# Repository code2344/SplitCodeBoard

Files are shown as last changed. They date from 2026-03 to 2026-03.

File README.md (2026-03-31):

# SplitCodeBoard

SplitCodeBoard is a split keyboard with a macropad designed for programming. I made this because I do not have any good keyboards at home, and the idea of a split keyboard appealed to me. 
SplitCodeBoard was made as part of Hack Club Stasis. "SplitCodeBoard.step" is the PCB STEP, the pcb with case is in 'SplitCodeBoard.step_STEP.zip'.
Here are some images: <br>
Macropad:<br>
Screenshot 2026-03-31 at 4 16 33 pm<br>
Left keyboard half:<br>
Screenshot 2026-03-31 at 4 17 09 pm<br>
Right keyboard half:<br>
Screenshot 2026-03-31 at 4 17 52 pm<br>
Side schematic:<br>
Screenshot 2026-03-31 at 4 19 14 pm<br>
Main and macropad schematic:<br>
Screenshot 2026-03-31 at 4 18 46 pm<br>
PCB:<br>
Screenshot 2026-03-31 at 4 20 12 pm<br>

## BOM
| Name | Purpose | Quantity | Total Cost (USD) | Link | Distributor |
|---|---|---|---|---|---|
| MCP23017-E/SO | GPIO expansion for the nRF52840 on the keyboard sides | 2 | 3.24 | [Link to listing](https://www.digikey.com/en/products/detail/microchip-technology/MCP23017-E-SO/894271) | Digikey |
| Seeed Xiao nRF52840 | Microcontrollers | 3 | 48.54 | [Link to listing](https://www.digikey.com.au/en/products/detail/seeed-technology-co-ltd/102010448/16652893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) | Digikey |
| Kailh PG1350 Choc V1 70PCS Mechanical Keyboard Switch Kailh Low Profile Switches Chocolate Mechanical Keyboard Switch RGB SMD 5-Pin Kailh Switches | Switches for the keyboard | 1 | 49.98 | [Link to listing](https://snapklik.com/en-au/product/kailh-pg1350-choc-v1-70pcs-mechanical-keyboard-switch-kailh-low-profile-switches-chocolate-mechanical-keyboard-switch-rgb-smd-5-pi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) | Snapklik |
| Kailh Choc Hotswap Sockets (Pack of 10) | Hotswap sockets for the keys | 7 | 24.5 | [Link to listing](https://keebd.com/products/kailh-choc-hotswap-sockets?variant=40393453338776&country=AU&currency=AUD) | KEEBD |
| PURFIELD 3.7V 501012 401010 401012 400909 Polymer Lithium Battery Suitable for I7 i8 i9 i10 Earphone Headset MP3 MP4 Toy GPS | Batteries for each half of the keyboard | 20 | 21.2 | [Link to listing](https://www.aliexpress.com/item/1005008747431465.html) | Aliexpress |
| 1N5819HW-7-F | Diodes for the key matrix | 70 | 17.15 | [Link to listing](https://www.digikey.com.au/en/products/detail/diodes-incorporated/1N5819HW-7-F/814970) | Digikey |

## Licensing

This repository uses split licensing by content type:

- Firmware and firmware configuration (for example, files under `zmk-config/`) are licensed under GNU Affero General Public License v3.0 only (`AGPL-3.0-only`).
- Hardware design files (for example, KiCad schematics/PCBs, footprints, and 3D mechanical files) are licensed under CERN Open Hardware Licence Version 2 - Strongly Reciprocal (`CERN-OHL-S-2.0`).

See the root `LICENSE` file for full licensing scope and notices.

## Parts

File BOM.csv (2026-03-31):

Name | Purpose | Quantity | Total Cost (USD) | Link | Distributor
MCP23017-E/SO | GPIO expansion for the nRF52840 on the keyboard sides | 2 | 3.24 | https://www.digikey.com/en/products/detail/microchip-technology/MCP23017-E-SO/894271 | Digikey
Seeed Xiao nRF52840 | Microcontrollers | 3 | 48.54 | https://www.digikey.com.au/en/products/detail/seeed-technology-co-ltd/102010448/16652893 | Digikey
Kailh PG1350 Choc V1 70PCS Mechanical Keyboard Switch Kailh Low Profile Switches Chocolate Mechanical Keyboard Switch RGB SMD 5-Pin Kailh Switches | Switches for the keyboard | 1 | 49.98 | https://snapklik.com/en-au/product/kailh-pg1350-choc-v1-70pcs-mechanical-keyboard-switch-kailh-low-profile-switches-chocolate-mechanical-keyboard-switch-rgb-s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 | Snapklik
Kailh Choc Hotswap Sockets (Pack of 10) | Hotswap sockets for the keys | 7 | 24.50 | https://keebd.com/products/kailh-choc-hotswap-sockets?variant=40393453338776&country=AU&currency=AUD | KEEBD
PURFIELD 3.7V 501012 401010 401012 400909 Polymer Lithium Battery Suitable for I7 i8 i9 i10 Earphone Headset MP3 MP4 Toy GPS | Batteries for each half of the keyboard | 20 | 21.20 | https://www.aliexpress.com/item/1005008747431465.html | Aliexpress
1N5819HW-7-F | Diodes for the key matrix | 70 | 17.15 | https://www.digikey.com.au/en/products/detail/diodes-incorporated/1N5819HW-7-F/814970 | Digikey

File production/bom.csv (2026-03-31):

Designator | Footprint | Quantity | Value | LCSC Part #
D1, D10, D11, D12, D13, D14, D15, D16, D17, D18, D19, D2, D20, D21, D22, D23, D24, D25, D26, D27, D28, D29, D3, D30, D31, D32, D33, D34, D35, D36, D37, D38, D39, D4, D40, D41, D42, D43, D44, D45, D46, D47, D48, D49, D5, D50, D51, D52, D53, D54, D55, D56, D6, D65, D66, D67, D68, D69, D7, D70, D8, D9 | D_SOD-123 | 62 | D
D57, D58, D59, D60, D61, D62, D63, D64 | LED_SK6812MINI_PLCC4_3.5x3.5mm_P1.75mm | 8 | SK6812MINI
J1 | SSD1306-0.91-OLED-4pin-128x32 | 1 | OLED
QR${REFERENCE} | httpsscstudios.tech | 1 | https://scstudios.tech
R1, R2, R3, R4, R7, R8 | 0201 | 6 | R
R5, R6 | 0603 | 2 | 10k
SW1, SW10, SW11, SW12, SW13, SW14, SW15, SW16, SW17, SW18, SW19, SW2, SW20, SW21, SW22, SW23, SW24, SW25, SW26, SW27, SW28, SW29, SW3, SW30, SW31, SW32, SW33, SW34, SW35, SW36, SW37, SW38, SW39, SW4, SW40, SW41, SW42, SW43, SW44, SW45, SW46, SW47, SW48, SW49, SW5, SW50, SW51, SW52, SW53, SW54, SW55, SW56, SW59, SW6, SW60, SW61, SW62, SW63, SW64, SW7, SW8, SW9 | SW_choc_v1_HS_CPG135001S30_1u | 62 | SW_Push
SW58 | RotaryEncoder_Alps_EC11E-Switch_Vertical_H20mm_MountingHoles | 1 | RotaryEncoder_Switch_MP
TP1, TP2, TP5 | TestPoint_Pad_2.0x2.0mm | 3 | BAT
TP3, TP4, TP6 | TestPoint_Pad_2.0x2.0mm | 3 | GND
U10, U5, U6 | TP4056-18650 | 3 | ~
U11, U7, U8 | SOT-23 | 3 | MCP1700x-330xxTT
U3, U4 | SOIC-28W_7.5x17.9mm_P1.27mm | 2 | MCP23017_SO

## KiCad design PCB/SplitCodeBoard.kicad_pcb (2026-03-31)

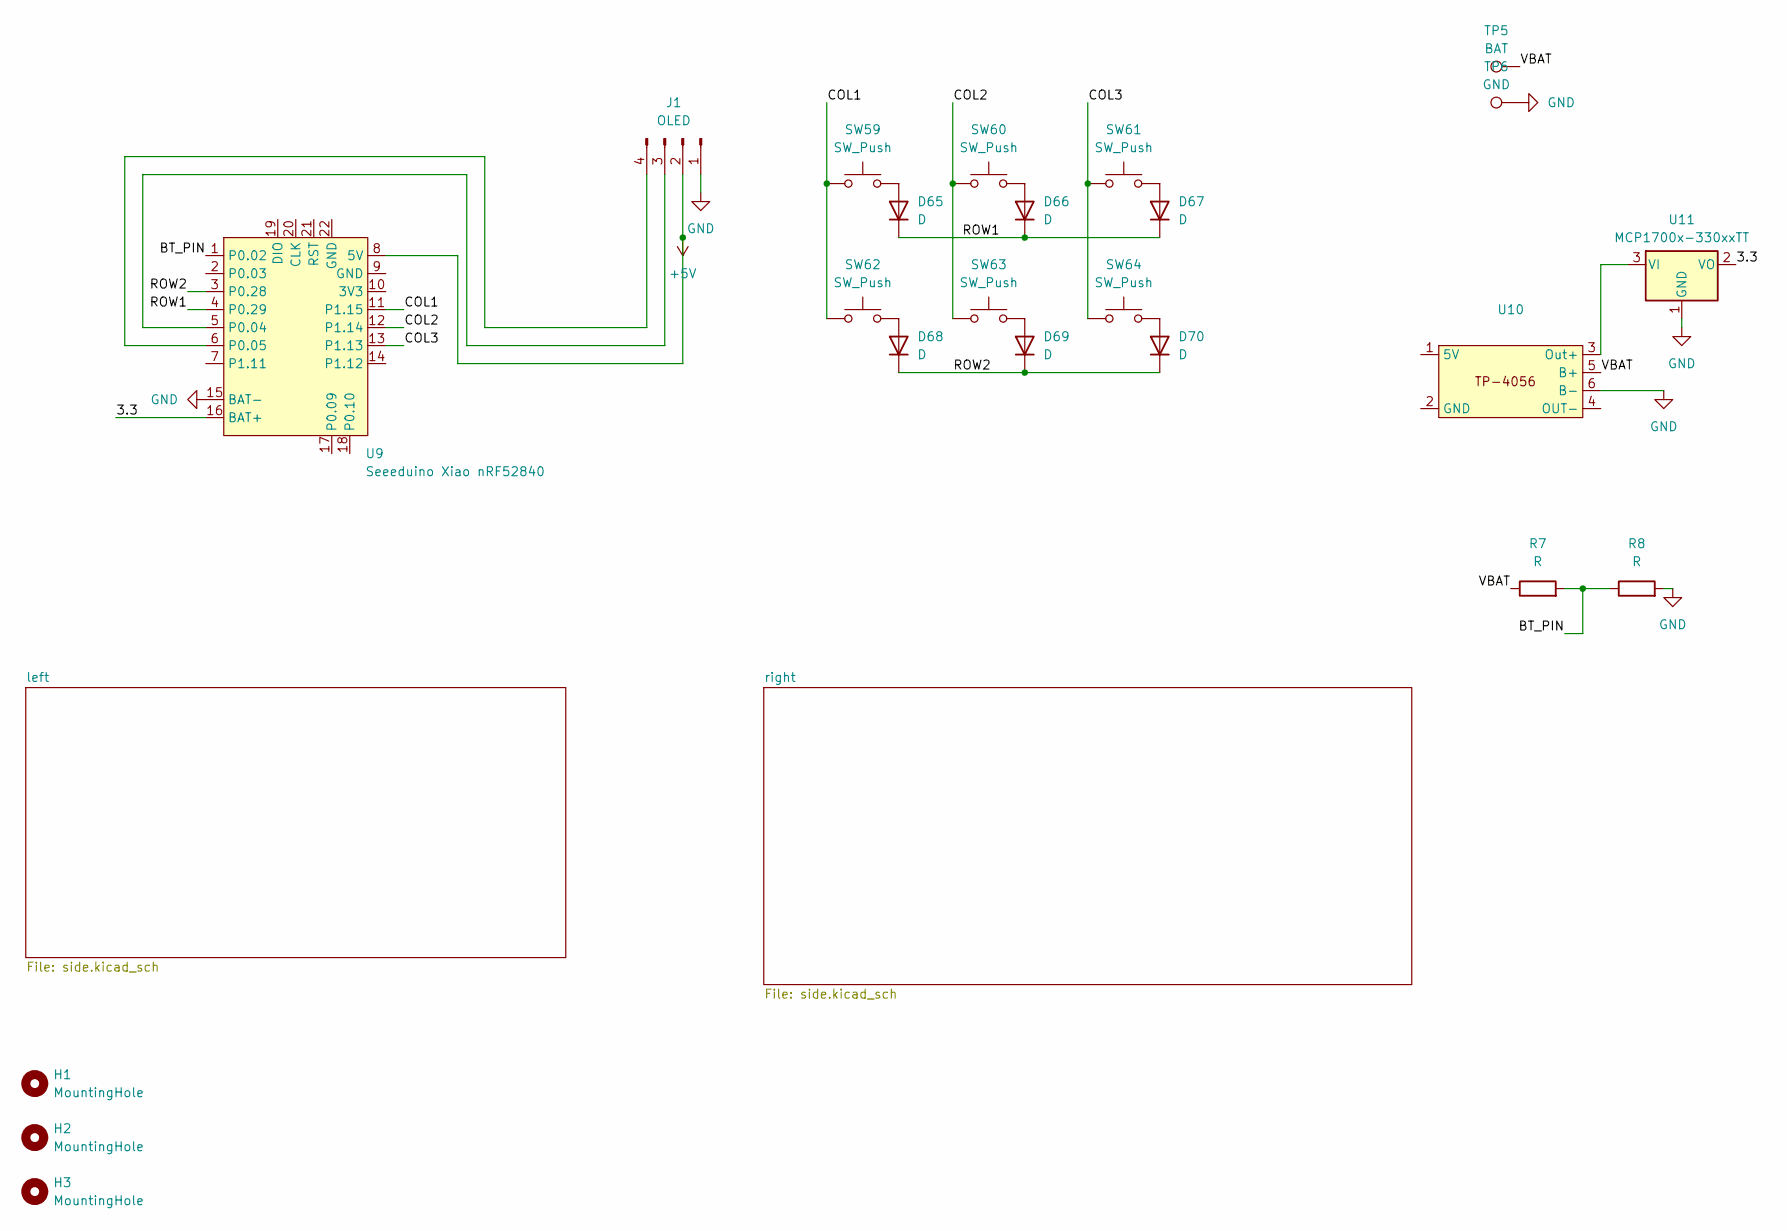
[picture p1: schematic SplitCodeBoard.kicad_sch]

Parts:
D65, D66, D67, D68, D69, D70: D; D_SOD-123
H1, H2, H3: MountingHole; MouseBite-Slot_2.0x2.0mm_inset_D0.5mm_P0.85mm_4h_Trace
J1: OLED; SSD1306-0.91-OLED-4pin-128x32
R7, R8: R; R_0201_0603Metric
SW59, SW60, SW61, SW62, SW63, SW64: SW_Push; SW_choc_v1_HS_CPG135001S30_1u
TP5: BAT; TestPoint_Pad_2.0x2.0mm
TP6: GND; TestPoint_Pad_2.0x2.0mm
U9: Seeeduino Xiao nRF52840; Xiao_nRF52840_ACH
U10: TP4056-18650
U11: MCP1700x-330xxTT; SOT-23

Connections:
+5V: J1.2, U9.8 (5V); also elsewhere on the board
/3.3: U9.16 (BAT+), U11.2 (VO)
/BT_PIN: R7.2, R8.1, U9.1 (P0.02)
/COL1: SW59.1, SW62.1, U9.11 (P1.15)
/COL2: SW60.1, SW63.1, U9.12 (P1.14)
/COL3: SW61.1, SW64.1, U9.13 (P1.13)
/ROW1: D65.1 (K), D66.1 (K), D67.1 (K), U9.4 (P0.29)
/ROW2: D68.1 (K), D69.1 (K), D70.1 (K), U9.3 (P0.28)
/VBAT: R7.1, TP5.1, U10.5 (B+)
GND: J1.1, R8.2, TP6.1, U9.15 (BAT-), U10.6 (B-), U11.1 (GND); also elsewhere on the board
unnamed: D65.2 (A), SW59.2
unnamed: D66.2 (A), SW60.2
unnamed: D67.2 (A), SW61.2
unnamed: D68.2 (A), SW62.2
unnamed: D69.2 (A), SW63.2
unnamed: D70.2 (A), SW64.2
unnamed: J1.3, U9.5 (P0.04)
unnamed: J1.4, U9.6 (P0.05)
unnamed: U10.3 (Out+), U11.3 (VI)

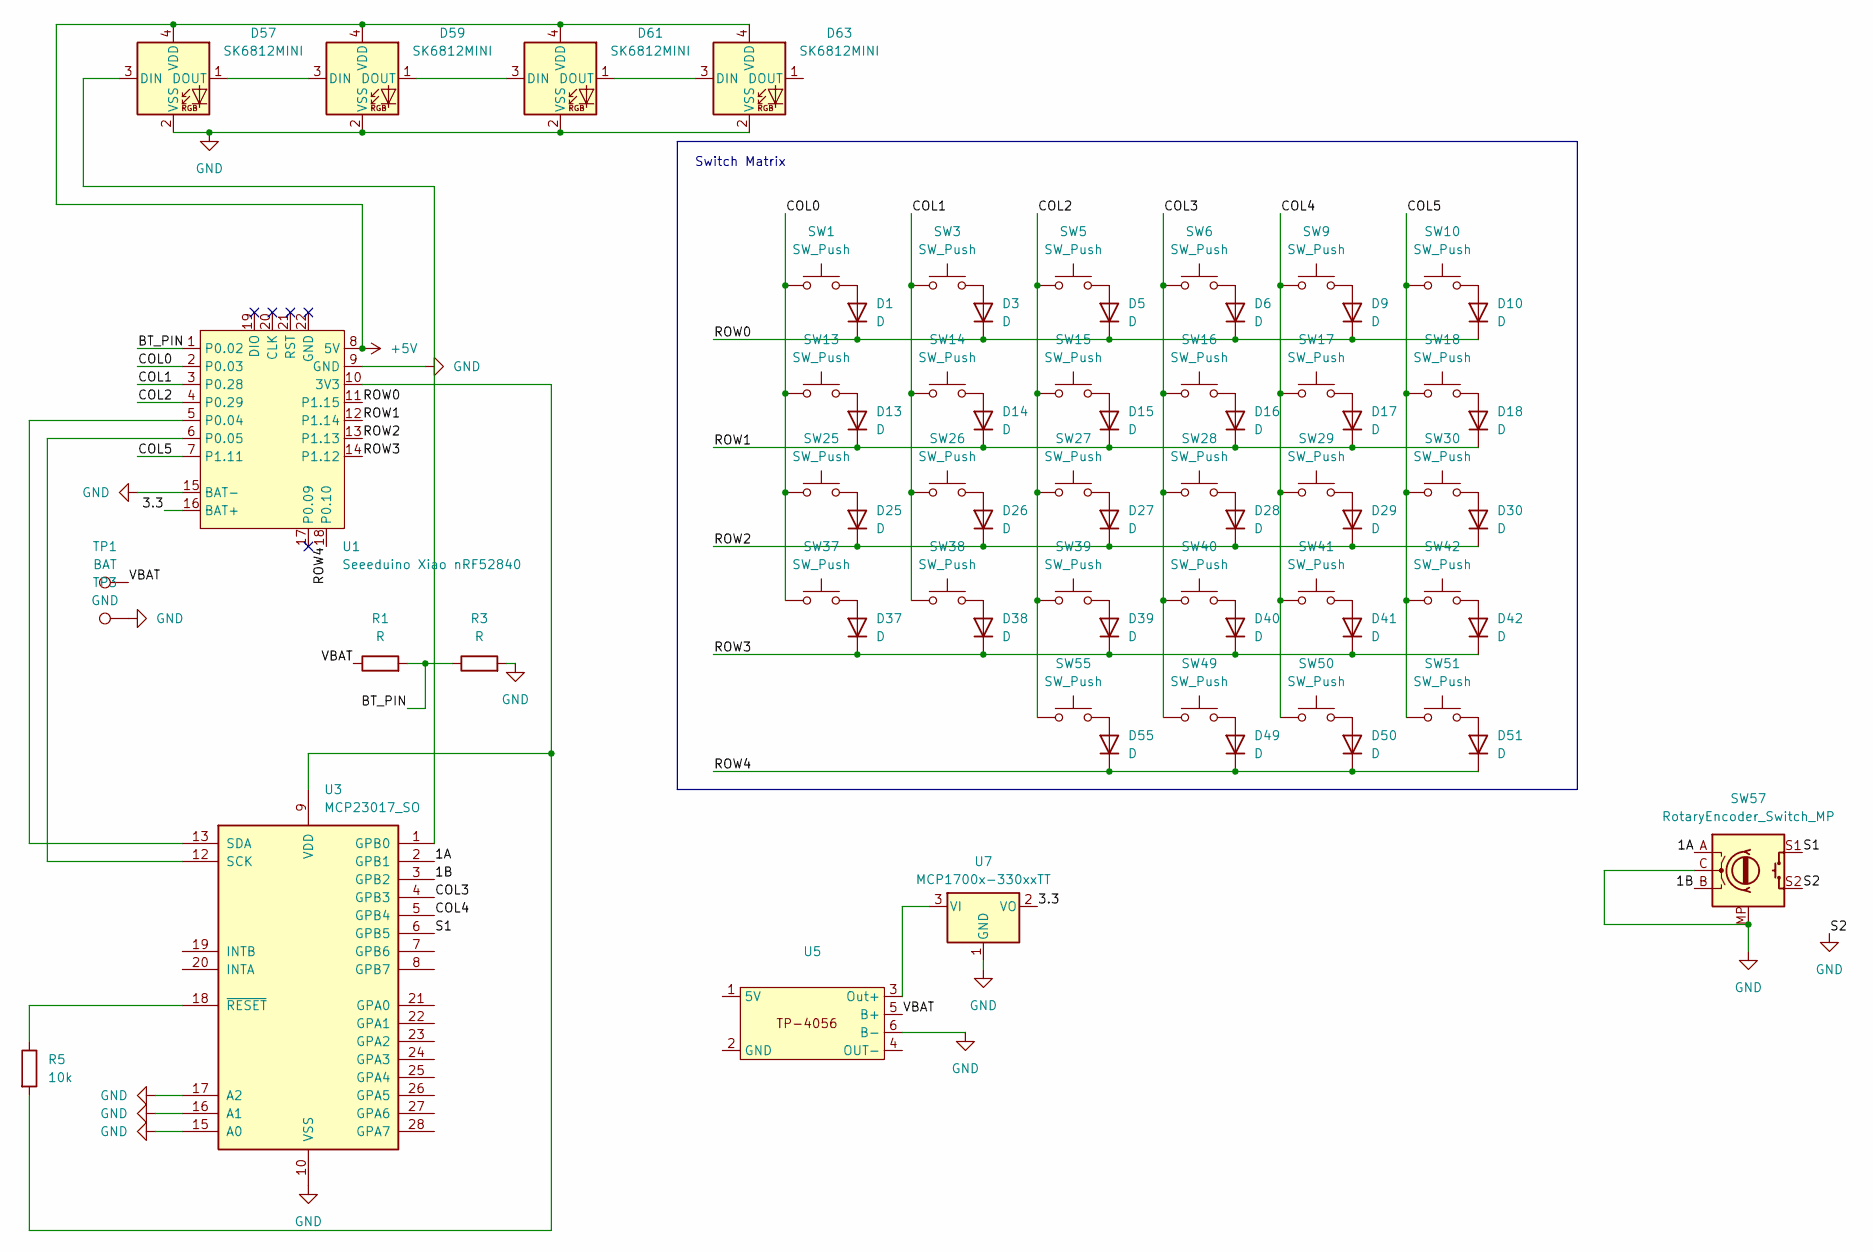
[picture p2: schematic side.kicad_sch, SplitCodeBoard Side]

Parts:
D1, D3, D5, D6, D9, D10, D13, D14, D15, D16, D17, D18, D25, D26, D27, D28, D29, D30, D37, D38, D39, D40, D41, D42, D49, D50, D51, D55: D; D_SOD-123
D57, D59, D61, D63: SK6812MINI; LED_SK6812MINI_PLCC4_3.5x3.5mm_P1.75mm
R1, R3: R; R_0201_0603Metric
R5: 10k; R_0603_1608Metric
SW1, SW3, SW5, SW6, SW9, SW10, SW13, SW14, SW15, SW16, SW17, SW18, SW25, SW26, SW27, SW28, SW29, SW30, SW37, SW38, SW39, SW40, SW41, SW42, SW49, SW50, SW51, SW55: SW_Push; SW_choc_v1_HS_CPG135001S30_1u
SW57: RotaryEncoder_Switch_MP; RotaryEncoder_Alps_EC11E-Switch_Vertical_H20mm_MountingHoles
TP1: BAT; TestPoint_Pad_2.0x2.0mm
TP3: GND; TestPoint_Pad_2.0x2.0mm
U1: Seeeduino Xiao nRF52840; Xiao_nRF52840_ACH
U3: MCP23017_SO; SOIC-28W_7.5x17.9mm_P1.27mm
U5: TP4056-18650
U7: MCP1700x-330xxTT; SOT-23

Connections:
+5V: D57.4 (VDD), D59.4 (VDD), D61.4 (VDD), D63.4 (VDD), U1.8 (5V); also elsewhere on the board
/left/3.3: U1.16 (BAT+), U7.2 (VO)
/left/BT_PIN: R1.2, R3.1, U1.1 (P0.02)
/left/COL0: SW1.1, SW13.1, SW25.1, SW37.1, U1.2 (P0.03)
/left/COL1: SW3.1, SW14.1, SW26.1, SW38.1, U1.3 (P0.28)
/left/COL2: SW5.1, SW15.1, SW27.1, SW39.1, SW55.1, U1.4 (P0.29)
/left/COL3: SW6.1, SW16.1, SW28.1, SW40.1, SW49.1, U3.4 (GPB3)
/left/COL4: SW9.1, SW17.1, SW29.1, SW41.1, SW50.1, U3.5 (GPB4)
/left/COL5: SW10.1, SW18.1, SW30.1, SW42.1, SW51.1, U1.7 (P1.11)
/left/ROW0: D1.1 (K), D3.1 (K), D5.1 (K), D6.1 (K), D9.1 (K), D10.1 (K), U1.11 (P1.15)
/left/ROW1: D13.1 (K), D14.1 (K), D15.1 (K), D16.1 (K), D17.1 (K), D18.1 (K), U1.12 (P1.14)
/left/ROW2: D25.1 (K), D26.1 (K), D27.1 (K), D28.1 (K), D29.1 (K), D30.1 (K), U1.13 (P1.13)
/left/ROW3: D37.1 (K), D38.1 (K), D39.1 (K), D40.1 (K), D41.1 (K), D42.1 (K), U1.14 (P1.12)
/left/ROW4: D49.1 (K), D50.1 (K), D51.1 (K), D55.1 (K), U1.18 (P0.10)
/left/VBAT: R1.1, TP1.1, U5.5 (B+)
GND: D57.2 (VSS), D59.2 (VSS), D61.2 (VSS), D63.2 (VSS), R3.2, TP3.1, U1.9 (GND), U1.15 (BAT-), U3.10 (VSS), U3.15 (A0), U3.16 (A1), U3.17 (A2), U5.6 (B-), U7.1 (GND); also elsewhere on the board
unnamed: D1.2 (A), SW1.2
unnamed: D3.2 (A), SW3.2
unnamed: D5.2 (A), SW5.2
unnamed: D6.2 (A), SW6.2
unnamed: D9.2 (A), SW9.2
unnamed: D10.2 (A), SW10.2
unnamed: D13.2 (A), SW13.2
unnamed: D14.2 (A), SW14.2
unnamed: D15.2 (A), SW15.2
unnamed: D16.2 (A), SW16.2
unnamed: D17.2 (A), SW17.2
unnamed: D18.2 (A), SW18.2
unnamed: D25.2 (A), SW25.2
unnamed: D26.2 (A), SW26.2
unnamed: D27.2 (A), SW27.2
unnamed: D28.2 (A), SW28.2
unnamed: D29.2 (A), SW29.2
unnamed: D30.2 (A), SW30.2
unnamed: D37.2 (A), SW37.2
unnamed: D38.2 (A), SW38.2
unnamed: D39.2 (A), SW39.2
unnamed: D40.2 (A), SW40.2
unnamed: D41.2 (A), SW41.2
unnamed: D42.2 (A), SW42.2
unnamed: D49.2 (A), SW49.2
unnamed: D50.2 (A), SW50.2
unnamed: D51.2 (A), SW51.2
unnamed: D55.2 (A), SW55.2
unnamed: D57.3 (DIN), U3.1 (GPB0)
unnamed: D57.1 (DOUT), D59.3 (DIN)
unnamed: D59.1 (DOUT), D61.3 (DIN)
unnamed: D61.1 (DOUT), D63.3 (DIN)
unnamed: R5.2, U1.10 (3V3), U3.9 (VDD)
unnamed: U1.5 (P0.04), U3.13 (SDA)
unnamed: U1.6 (P0.05), U3.12 (SCK)
unnamed: R5.1, U3.18 (~RESET)
unnamed: U5.3 (Out+), U7.3 (VI)

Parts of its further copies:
D2, D4, D7, D8, D11, D12, D19, D20, D21, D22, D23, D24, D31, D32, D33, D34, D35, D36, D43, D44, D45, D46, D47, D48, D52, D53, D54, D56: D; D_SOD-123
D58, D60, D62, D64: SK6812MINI; LED_SK6812MINI_PLCC4_3.5x3.5mm_P1.75mm
R2, R4: R; R_0201_0603Metric
R6: 10k; R_0603_1608Metric
SW2, SW4, SW7, SW8, SW11, SW12, SW19, SW20, SW21, SW22, SW23, SW24, SW31, SW32, SW33, SW34, SW35, SW36, SW43, SW44, SW45, SW46, SW47, SW48, SW52, SW53, SW54, SW56: SW_Push; SW_choc_v1_HS_CPG135001S30_1u
SW58: RotaryEncoder_Switch_MP; RotaryEncoder_Alps_EC11E-Switch_Vertical_H20mm_MountingHoles
TP2: BAT; TestPoint_Pad_2.0x2.0mm
TP4: GND; TestPoint_Pad_2.0x2.0mm
U2: Seeeduino Xiao nRF52840; Xiao_nRF52840_ACH
U4: MCP23017_SO; SOIC-28W_7.5x17.9mm_P1.27mm
U6: TP4056-18650
U8: MCP1700x-330xxTT; SOT-23

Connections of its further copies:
+5V: D58.4 (VDD), D60.4 (VDD), D62.4 (VDD), D64.4 (VDD), U2.8 (5V); also elsewhere on the board
/right/3.3: U2.16 (BAT+), U8.2 (VO)
/right/BT_PIN: R2.2, R4.1, U2.1 (P0.02)
/right/COL0: SW2.1, SW19.1, SW31.1, SW43.1, U2.2 (P0.03)
/right/COL1: SW4.1, SW20.1, SW32.1, SW44.1, U2.3 (P0.28)
/right/COL2: SW7.1, SW21.1, SW33.1, SW45.1, SW56.1, U2.4 (P0.29)
/right/COL3: SW8.1, SW22.1, SW34.1, SW46.1, SW52.1, U4.4 (GPB3)
/right/COL4: SW11.1, SW23.1, SW35.1, SW47.1, SW53.1, U4.5 (GPB4)
/right/COL5: SW12.1, SW24.1, SW36.1, SW48.1, SW54.1, U2.7 (P1.11)
/right/ROW0: D2.1 (K), D4.1 (K), D7.1 (K), D8.1 (K), D11.1 (K), D12.1 (K), U2.11 (P1.15)
/right/ROW1: D19.1 (K), D20.1 (K), D21.1 (K), D22.1 (K), D23.1 (K), D24.1 (K), U2.12 (P1.14)
/right/ROW2: D31.1 (K), D32.1 (K), D33.1 (K), D34.1 (K), D35.1 (K), D36.1 (K), U2.13 (P1.13)
/right/ROW3: D43.1 (K), D44.1 (K), D45.1 (K), D46.1 (K), D47.1 (K), D48.1 (K), U2.14 (P1.12)
/right/ROW4: D52.1 (K), D53.1 (K), D54.1 (K), D56.1 (K), U2.18 (P0.10)
/right/VBAT: R2.1, TP2.1, U6.5 (B+)
GND: D58.2 (VSS), D60.2 (VSS), D62.2 (VSS), D64.2 (VSS), R4.2, SW58.C, SW58.MP, SW58.S2, TP4.1, U2.9 (GND), U2.15 (BAT-), U4.10 (VSS), U4.15 (A0), U4.16 (A1), U4.17 (A2), U6.6 (B-), U8.1 (GND); also elsewhere on the board
unnamed: D2.2 (A), SW2.2
unnamed: D4.2 (A), SW4.2
unnamed: D7.2 (A), SW7.2
unnamed: D8.2 (A), SW8.2
unnamed: D11.2 (A), SW11.2
unnamed: D12.2 (A), SW12.2
unnamed: D19.2 (A), SW19.2
unnamed: D20.2 (A), SW20.2
unnamed: D21.2 (A), SW21.2
unnamed: D22.2 (A), SW22.2
unnamed: D23.2 (A), SW23.2
unnamed: D24.2 (A), SW24.2
unnamed: D31.2 (A), SW31.2
unnamed: D32.2 (A), SW32.2
unnamed: D33.2 (A), SW33.2
unnamed: D34.2 (A), SW34.2
unnamed: D35.2 (A), SW35.2
unnamed: D36.2 (A), SW36.2
unnamed: D43.2 (A), SW43.2
unnamed: D44.2 (A), SW44.2
unnamed: D45.2 (A), SW45.2
unnamed: D46.2 (A), SW46.2
unnamed: D47.2 (A), SW47.2
unnamed: D48.2 (A), SW48.2
unnamed: D52.2 (A), SW52.2
unnamed: D53.2 (A), SW53.2
unnamed: D54.2 (A), SW54.2
unnamed: D56.2 (A), SW56.2
unnamed: D58.3 (DIN), U4.1 (GPB0)
unnamed: D58.1 (DOUT), D60.3 (DIN)
unnamed: D60.1 (DOUT), D62.3 (DIN)
unnamed: D62.1 (DOUT), D64.3 (DIN)
unnamed: R6.2, U2.10 (3V3), U4.9 (VDD)
unnamed: U2.5 (P0.04), U4.13 (SDA)
unnamed: U2.6 (P0.05), U4.12 (SCK)
unnamed: R6.1, U4.18 (~RESET)
unnamed: U6.3 (Out+), U8.3 (VI)

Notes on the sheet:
Switch Matrix

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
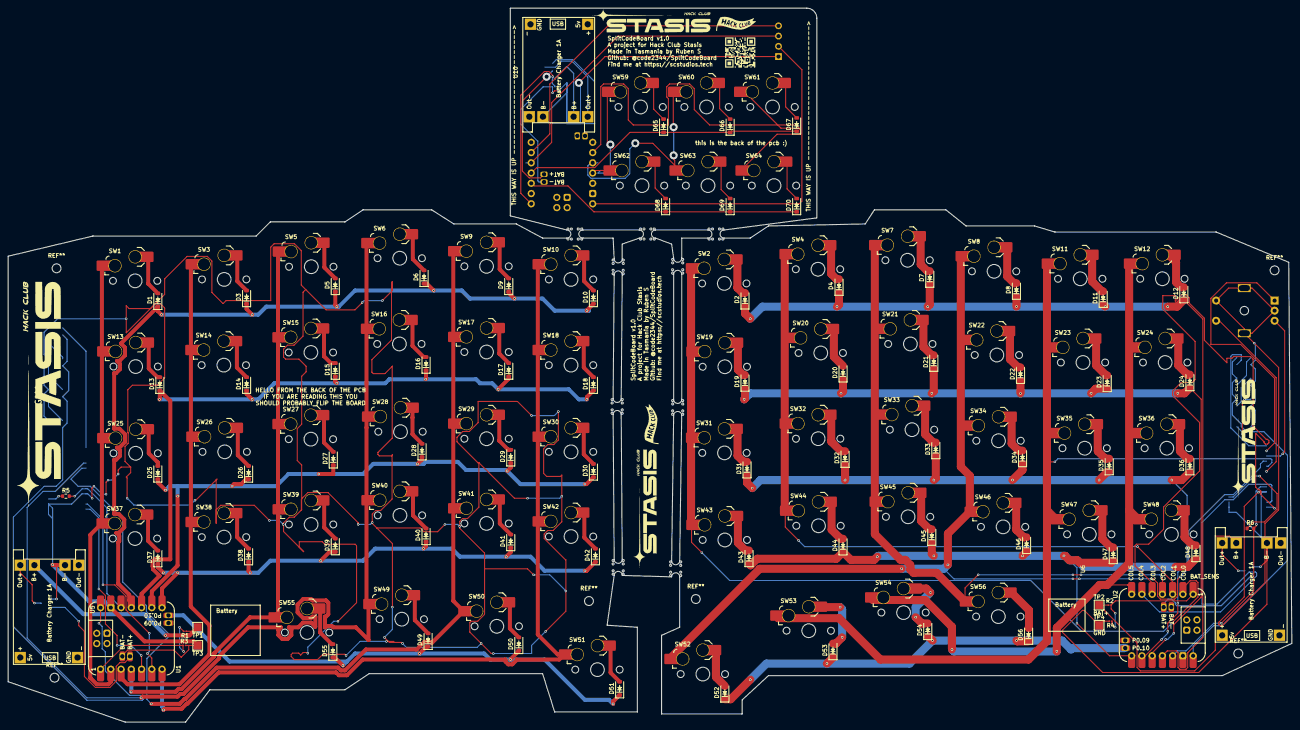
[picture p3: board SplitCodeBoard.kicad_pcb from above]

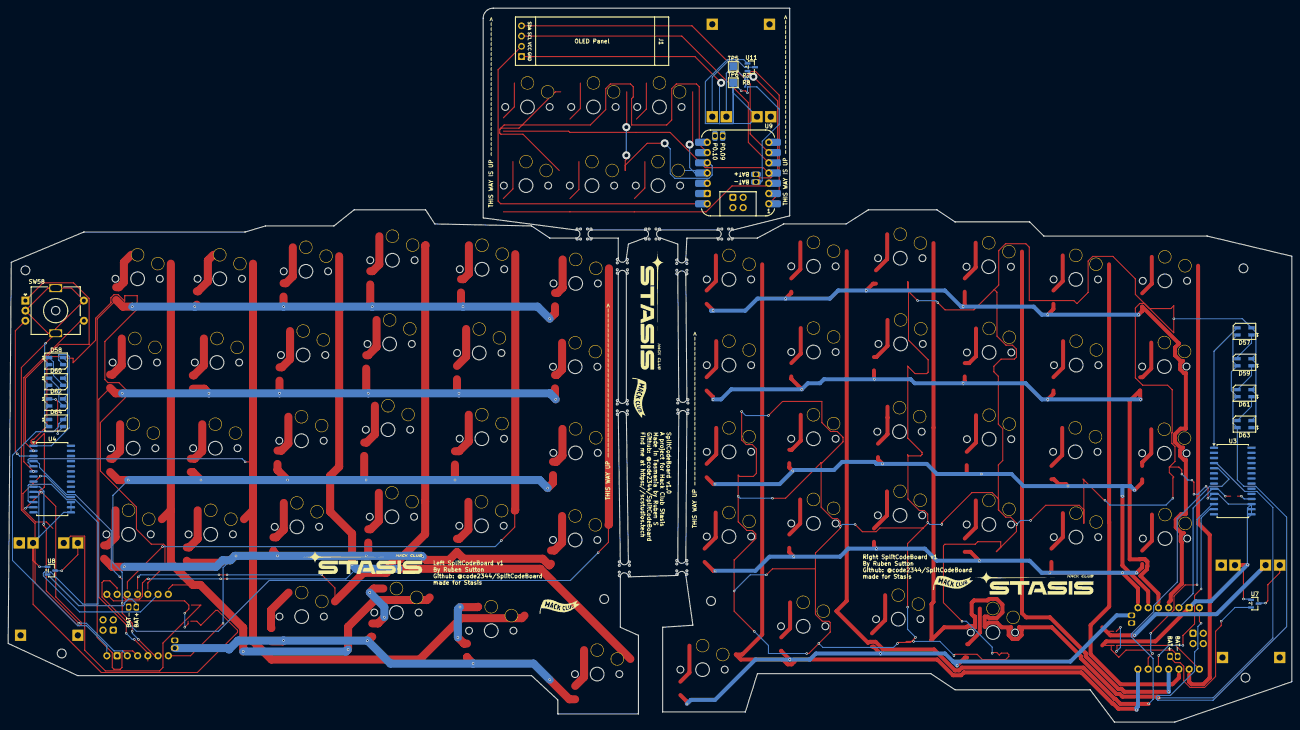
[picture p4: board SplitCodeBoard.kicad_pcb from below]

Board: 2 copper layers, 318.3 x 177.0 mm, 169 parts (20 on the bottom side), 124 nets.

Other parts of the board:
H1#2, H1#3, H1#4, H1#5, H1#6, H1#7: MountingHole; MouseBite-Slot_2.0x2.0mm_inset_D0.5mm_P0.85mm_4h_Trace
QR${REFERENCE}: https://scstudios.tech; httpsscstudios.tech

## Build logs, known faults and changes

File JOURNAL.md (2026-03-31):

<!--
  This journal was auto generated by Stasis.
-->

# 3/31/2026 5 AM - Finished the macropad!!!!! I'm pretty sure that i'm done

_Time spent: 1h_

I finally finished the macropad. Only need a sanity check now (and i'm sure i'll figure out another issue as soon as it arrives) but I'm done!!! It took a while, and i had trouble because it couldn't chamfer some edges (apparently it is too complicated). 
Screenshot 2026-03-31 at 4.09.51 pm
I plan to put a laser-engraved piece of mdf or wood where that rectangular hole is. 

Screenshot 2026-03-31 at 4.11.14 pm




# 3/27/2026 9 AM - Almost finished the case

_Time spent: 2h_

I've finished working on the main keyboard case parts, I only have the macropad left. I may well be done soon. Also, I have no idea how I did the cool fillets on the other side, so now it's totally a deliberate design choice to have the sides not be identical... :)

Screenshot 2026-03-27 at 8.05.22 pm

Screenshot 2026-03-27 at 8.06.27 pm




# 3/16/2026 10 PM - Worked more on the case, and added a plate

_Time spent: 2.5h_

I did a lot more work on the case, and I also did some research about keyboards. I didn't realise I needed a plate, but I've added it now. I'm still not sure which model of the choc switch I want to use yet. 
I plan to CNC the case and laser cut the shell. It will be out of solid wood. 
## right side (with shell)
Screenshot 2026-03-17 at 9.46.28 am

## right side without shell
Screenshot 2026-03-17 at 9.47.54 am

Screenshot 2026-03-17 at 9.48.12 am

right side with texture:








# 3/15/2026 9 AM - Added key models to help me design the case and added some graphics

_Time spent: 0.75h_

I added models of the switch to the footprint, which means I can work much easier in Shapr3D on the case.  (a downside to this is I have to start from scratch on the case but oh well) 
I also added heaps of decoration and the hack club logos! I also did a lot of research about the key models, and where I am going to buy the hotswappable sockets and the switches themselves, as Kailh no longer sell the Choc v1, only the v2. I'm quite happy with the end result. I would have gone with v2 because their datasheet is more accessible and I can actually buy them from the manufacturer but the v1s ended up cheaper anyway and I really cannot be bothered rerouting the entire pcb.
Screenshot 2026-03-15 at 8.41.22 pm

Screenshot 2026-03-15 at 8.41.45 pm

Screenshot 2026-03-15 at 8.41.55 pm

Screenshot 2026-03-15 at 8.42.15 pm

Screenshot 2026-03-15 at 8.42.35 pm







# 3/13/2026 10 AM - Worked on the firmware

_Time spent: 3h_

I started the firmware dor it. I only did 40m of actual coding but i spent quite a while reading docs.
I chose to use ZMK for the firmware.
Screenshot 2026-03-13 at 9.11.30 pm

Screenshot 2026-03-13 at 9.11.51 pm




# 3/12/2026 10 AM - Started case for the macropad

_Time spent: 1.4h_

I started designing the case for the macropad (and the main keyboard) in Shapr3D, I think it now looks really good! 
Screenshot 2026-03-12 at 9.33.51 pm

Screenshot 2026-03-12 at 9.34.05 pm

Screenshot 2026-03-12 at 9.34.35 pm





# 3/12/2026 3 AM - pain (i had to delete all the per-key rgb because i put the hotswap sockets on backwards) also i added a macropad

_Time spent: 3.25h_

I deleted the per-key rgb after i realised that the hotswap sockets are meant to be on the bottom :( 
so I decided I will just flip the pcb over when i get it. I also added a macropad with 6 keys and an oled display. 
# Macropad:
Screenshot 2026-03-12 at 2.32.53 pm
# Full PCB
Screenshot 2026-03-12 at 2.33.08 pm




# 3/11/2026 9 AM - Added per-key rgb, extra leds, and rotary encoder for volume

_Time spent: 3.5h_

I added a rotary encoder (with switch) so i can control volume and play/pause as well as move (it will move playhead in things like premiere pro and davinci resolve) and per key rgb leds so it will look cool as well as custom leds.
I also added proper battery management, and I'll use something like this for the battery: [LINK](https://www.aliexpress.com/item/1005008747431465.html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"order"%3A"62"%2C"eval"%3A"1"%2C"fromPage"%3A"search"%7D&pdp_npi=6%40dis%21AUD%2124.70%2117.29%21%21%21118.46%2182.92%21%402103129017731876810187373e8420%2112000046500553005%21sea%21AU%210%21ABX%211%210%21n_tag%3A-29910%3Bd%3A127d489c%3Bm03_new_user%3A-29895&curPageLogUid=fbv5AXs7y9yj&utparam-url=scene%3Asearch%7Cquery_from%3A%7Cx_object_id%3A1005008747431465%7C_p_origin_prod%3A&search_p4p_id=20260310170801936522889667640000114178_1)

Screenshot 2026-03-11 at 8.50.38 pm

Screenshot 2026-03-11 at 8.50.58 pm




# 3/10/2026 11 PM - Working on the top plate for the case

_Time spent: 0.1666666666666667h_

I worked a little bit on the top plate for the case. 
Screenshot 2026-03-11 at 10.57.14 am






# 3/10/2026 9 AM - Worked a bit on the case

_Time spent: 1h_

I worked on the design for the case. I'm still not 100% certain if the key is 16.5cm2 but i think it is. 

https://app.shapr3d.com/p/ec1575ae-bfcf-46b0-960c-466677e8bdd8

Screenshot 2026-03-10 at 8.27.20 pm

Screenshot 2026-03-10 at 8.31.18 pm

Screenshot 2026-03-10 at 8.31.49 pm

I tried to record it on lapse but it didnt work it keeps glitching and not saving





# 3/10/2026 7 AM - Designed and Routed the PCB

_Time spent: 3.5h_

I designed the schematic for the keyboard and routed the keyboard PCB.
I am still going to add some more buttons and some LEDs but I don't know where to wire them, I might need a different chip.
Screenshot 2026-03-10 at 6.53.16 pm

Screenshot 2026-03-10 at 6.54.03 pm

(forgot to start lapse so it's only about 30m long)




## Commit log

2026-03-12 more stuff
    [SplitCodeBoard.kicad_pcb, SplitCodeBoard.kicad_sch, side.kicad_sch]
2026-03-15 Add SplitCodeBoard macropad support and configuration files
    - Created package.json to include dependency on xpm.
    - Added Kconfig for SplitCodeBoard macropad to define board configuration.
    - Documented layout and wiring notes for the SplitCodeBoard in layouts file.
    - Created device tree overlay for SplitCodeBoard macropad with GPIO configurations.
    - Added default configuration file for SplitCodeBoard macropad enabling GPIO and BLE support.
    - Added a lock file for the SplitCodeBoard schematic.
2026-03-31 Uploading BOM
    [Split CodeBoard-bom.csv]
2026-03-31 Added Case
    [SplitCodeBoard.kicad_pcb, SplitCodeBoard.kicad_sch, bom.csv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]
2026-03-31 Rename Split CodeBoard-bom.csv to BOM.csv
    [BOM.csv]
2026-03-31 moved pcb stuff to a folder
    [SplitCodeBoard.kicad_pcb, SplitCodeBoard.kicad_sch, side.kicad_sch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]
